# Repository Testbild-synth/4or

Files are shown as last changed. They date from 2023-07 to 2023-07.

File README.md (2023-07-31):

# 4OR
4x logical OR combiner - Passive 8HP Eurorack Module - Designed by Krach der Roboter

This module was commissioned by Krach der Roboter as a passive performance tool/utility helper.
It is basically 4 inputs that you can use to combine logical signals. Using diodes, the outputs function as logical sums (or OR combiners) of the
input signals. It is meant to be as easy as possible to serve as an entry-level kit for building during trade fairs, workshops etc.

## STATUS: v1.1 verified working!

## Hardware
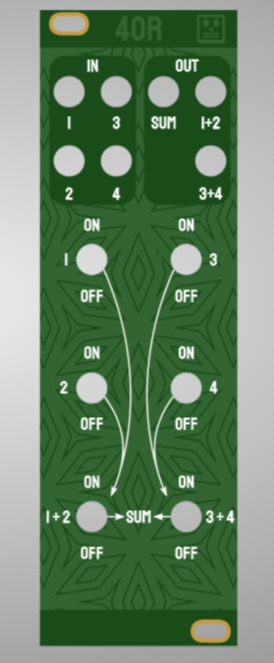
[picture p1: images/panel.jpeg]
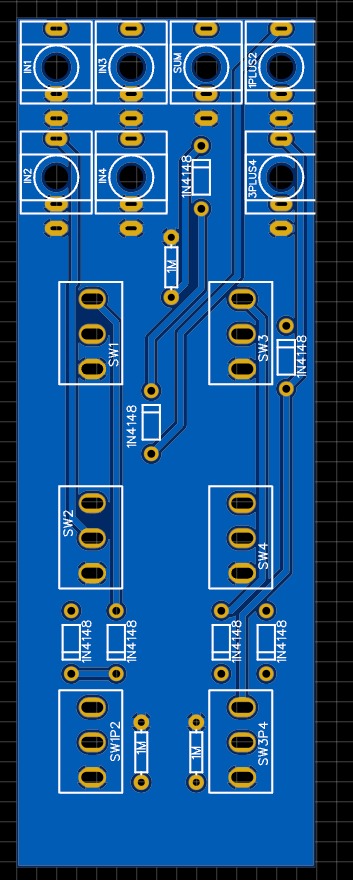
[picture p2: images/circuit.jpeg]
  

The "gerbers" folder contains the files for the PCB and the panel. You can order it from any PCB maker, we use JLC. Since there is no exposed copper on the panel, you can order it in any material/color combination that suits you.
Switches are 2-toggle ON/ON switches (without the middle position). Most other components are standard and should be trivial to source.

Have fun building :)

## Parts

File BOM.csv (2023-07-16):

ID | Name | Designator | Footprint | Quantity | Manufacturer Part | Manufacturer
1 | 1N4148 | D1,D2,D3,D4,D5,D6,D7 | DO-35_BD2.0-L4.0-P8.00-D0.5-FD | 7 | 1N4148 | SEMTECH
2 | IN1 | J1 | THONKICONN_1 | 1 | PJ-301BM | Tayda Electronics
3 | IN2 | J2 | THONKICONN_1 | 1 | PJ-301BM | Tayda Electronics
4 | IN3 | J3 | THONKICONN_1 | 1 | PJ-301BM | Tayda Electronics
5 | IN4 | J4 | THONKICONN_1 | 1 | PJ-301BM | Tayda Electronics
6 | 1PLUS2 | J5 | THONKICONN_1 | 1 | PJ-301BM | Tayda Electronics
7 | 3PLUS4 | J6 | THONKICONN_1 | 1 | PJ-301BM | Tayda Electronics
8 | SUM | J7 | THONKICONN_1 | 1 | PJ-301BM | Tayda Electronics
9 | 1M | R1,R2,R3 | R_AXIAL-0.3 | 3
10 | SW1 | U1 | MINI TOGGLE SWITCH SPDT ON-ON | 1 | Mini Toggle Switch SPDT On-On | Tayda Electronics
11 | SW2 | U2 | MINI TOGGLE SWITCH SPDT ON-ON | 1 | Mini Toggle Switch SPDT On-On | Tayda Electronics
12 | SW3 | U3 | MINI TOGGLE SWITCH SPDT ON-ON | 1 | Mini Toggle Switch SPDT On-On | Tayda Electronics
13 | SW4 | U4 | MINI TOGGLE SWITCH SPDT ON-ON | 1 | Mini Toggle Switch SPDT On-On | Tayda Electronics
14 | SW1P2 | U5 | MINI TOGGLE SWITCH SPDT ON-ON | 1 | Mini Toggle Switch SPDT On-On | Tayda Electronics
15 | SW3P4 | U6 | MINI TOGGLE SWITCH SPDT ON-ON | 1 | Mini Toggle Switch SPDT On-On | Tayda Electronics

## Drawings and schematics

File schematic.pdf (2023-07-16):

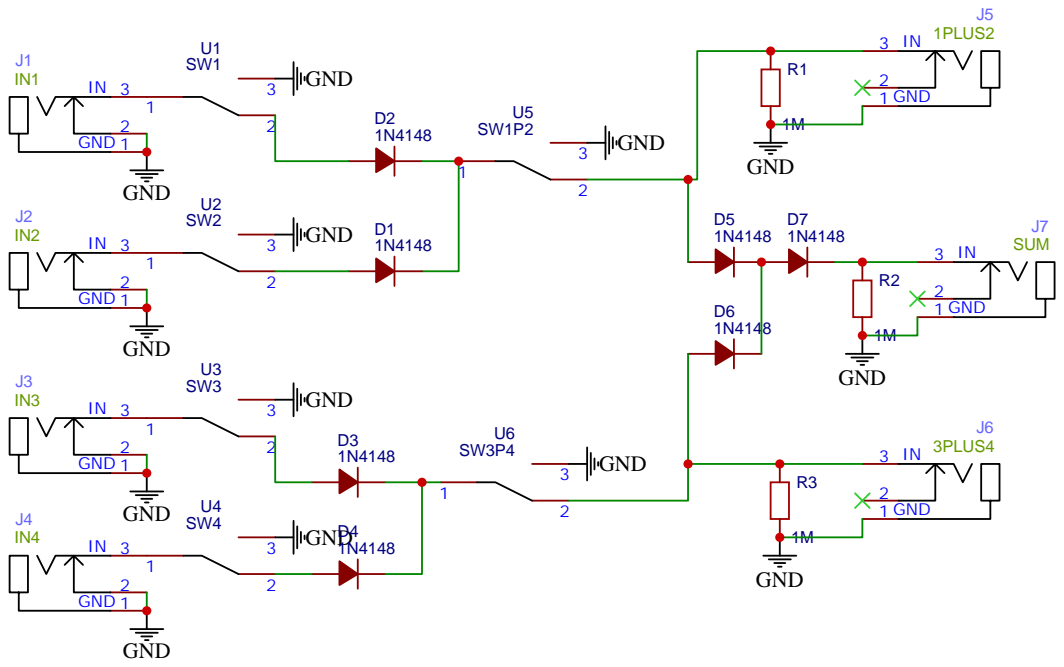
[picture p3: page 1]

Company: Krach der Roboter

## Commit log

2023-07-17 version with non-grounded switches
    [circuit_pcb.kicad_pcb]
2023-07-17 fixed one small error
    [circuit_pcb.kicad_pcb]
2023-07-31 fixed switch orientation
    [circuit_pcb.kicad_pcb]
2023-07-31 version 1.2 with bottom row connector
    [circuit_pcb.kicad_pcb]
2023-07-31 fixed typo on silkscreen
2023-08-03 added line marker to connector
